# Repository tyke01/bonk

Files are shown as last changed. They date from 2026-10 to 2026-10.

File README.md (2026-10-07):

# BONK

**An open-source handheld RC transmitter built around the ESP32.**
Designed by Spectral Systems.

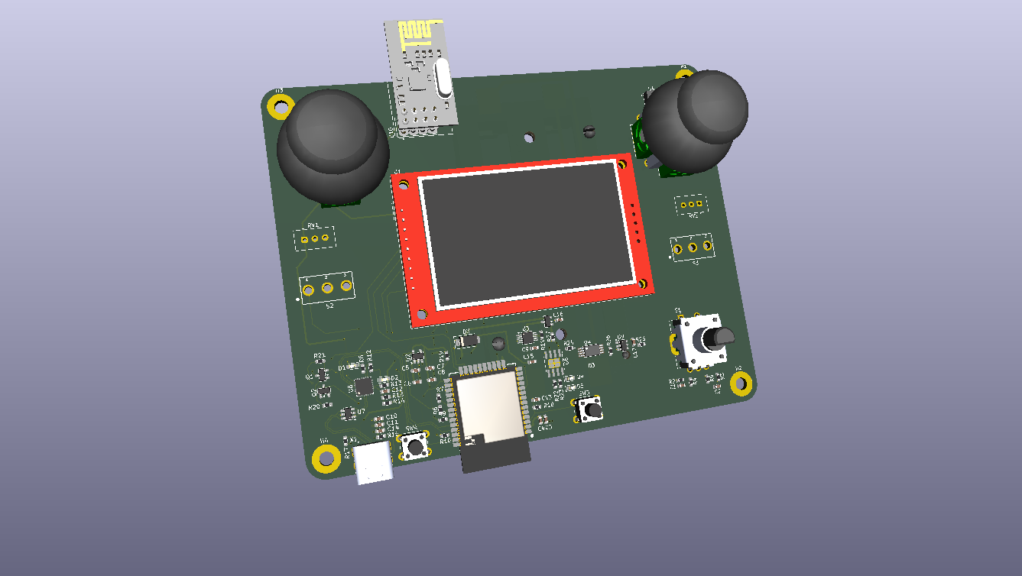
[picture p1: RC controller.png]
BONK PCB render


> **Status: Rev 1 (first PCB revision).** The schematic passes ERC with 0 errors and the PCB passes DRC. Boards have been ordered but **not yet assembled or tested**, so expect errata. See [Known issues](#known-issues-rev-1) before building one.

---

## Contents

- [Features](#features)
- [Repository layout](#repository-layout)
- [Hardware overview](#hardware-overview)
- [Power architecture](#power-architecture)
- [ESP32 pin map](#esp32-pin-map)
- [Buses and addresses](#buses-and-addresses)
- [Firmware notes](#firmware-notes)
- [Bill of materials](#bill-of-materials)
- [Manufacturing](#manufacturing)
- [Assembly](#assembly)
- [Bring-up checklist](#bring-up-checklist)
- [Known issues (Rev 1)](#known-issues-rev-1)
- [License](#license)

---

## Features

- **MCU:** ESP32 module (Ai-Thinker ESP32-SL) with on-board PCB antenna
- **Inputs:** 2 analog joysticks, 2 potentiometers, 2 toggle switches, a rotary encoder with push switch, and BOOT/EN buttons
- **Display:** 2.8" ILI9341 320x240 SPI TFT module (its SD card slot is not used)
- **Radio:** nRF24L01 breakout on the shared SPI bus. ESP-NOW/WiFi/BLE are also available from the ESP32 itself
- **USB-C:** programming and charging through a CP2102N USB-UART bridge with automatic reset into the bootloader
- **Battery:** 2x 18650 cells in parallel (1S), with a TP4056 charger, DW01A + FS8205A protection, and USB/battery load sharing
- **Battery monitoring:** INA226 voltage and current monitor on I2C, which measures both charge and discharge current
- **PCB:** 4 layers, 125 x 100 mm, 1.6 mm thick

---

## Repository layout

```
RC controller.kicad_pro     KiCad project
RC controller.kicad_sch     Schematic (single sheet, with design notes)
RC controller.kicad_pcb     PCB layout
RC controller.png           3D render
bom/
  ibom.html                 Interactive BOM (open in a browser for assembly)
  RC controller.csv         Raw BOM export
production/
  RC_controller.zip         Gerbers + drill files, ready to upload to JLCPCB
  bom.csv                   BOM for JLCPCB assembly
  positions.csv             Pick-and-place (CPL) file
  designators.csv
  netlist.ipc               IPC netlist (lets the fab run electrical tests)
placement/
  RC controller-all.pos     KiCad component placement file
```

Designed in **KiCad 10.0.6**. Open `RC controller.kicad_pro` to view everything.

---

## Hardware overview

| Block | Main parts | Notes |
|---|---|---|
| MCU | L1 ESP32-SL | Antenna overhangs the bottom board edge |
| USB-UART | U8 CP2102N (QFN-24), Q1/Q2 BC817 | DTR/RTS drive EN and IO0 for automatic bootloader entry |
| USB-C | X1 GCT USB4085-GF-A, U7 USBLC6-2SC6 | 5.1k pull-downs on CC1/CC2 (sink, default 5 V). USBLC6 provides ESD protection on D+/D- |
| Charger | U6 TP4056 (ESOP-8) | About 1.1 A charge current, set by R24 |
| Protection | U9 DW01A, Q4 FS8205A | Disconnects the cells on overcharge, overdischarge, or overcurrent |
| Load sharing | Q3 AO3401A, D3 SS34 | Runs the system from USB when plugged in, otherwise from the battery |
| Regulator | U2 AP2112K-3.3 | 600 mA LDO, single 3.3 V rail for everything |
| Battery monitor | U3 INA226, R11 20 mΩ | I2C address 0x40 |
| Display | U1 ILI9341 2.8" SPI module | Powered from 3.3 V |
| Radio | U10 nRF24L01 breakout | Shares the SPI bus with the display |
| Sticks | U4/U5 SparkFun COM-09032 | Powered from 3.3 V |
| Pots | RV1/RV2 | Powered from 3.3 V |
| Encoder | S1 Bourns PEC12R-4217F-S0024 | 10k pull-ups plus 10k/10 nF RC hardware debounce |
| Toggles | S2/S3 Würth 472123010111 | Switch to GND |
| Buttons | SW3 (EN/reset), SW4 (BOOT) | R18/C13 delay the release of EN at power-up |
| Battery holder | BT1 Keystone 1048 | 2x 18650, **mounted on the bottom side** |

---

## Power architecture

### Net names

| Net | What it is |
|---|---|
| `+5V` | USB VBUS |
| `+VBAT_IN` | Cell positive terminal |
| `BAT_P` | Battery positive after the shunt. Charger output and Q3 drain connect here |
| `+VBAT_OUT` | **System rail (VSYS).** Feeds the 3.3 V regulator |
| `+3V3` | Regulated 3.3 V for all logic |
| `BAT-` | Raw cell negative |
| `GND` | System ground (the switched negative, P-). Connected to `BAT-` through Q4 |

### Charging path

`TP4056 BAT → BAT_P → R11 shunt → +VBAT_IN → cells → BAT- → Q4 (FS8205A) → GND → back to the TP4056`

The return path goes through the protection MOSFETs. That's what allows the DW01A to stop charging if a cell reaches its overcharge limit.

### Load sharing

- **USB connected:** 5 V feeds `+VBAT_OUT` through D3 (about 4.5 V). Q3's gate sits at 5 V, so Q3 is off, and its body diode is reverse biased. The battery is isolated from the load and only the charger talks to it. Charge termination is therefore not confused by system current.
- **USB disconnected:** R27 pulls Q3's gate to GND, Q3 turns on, and the battery powers `+VBAT_OUT` through Q3's low channel resistance. D3 blocks the battery from back-feeding the USB side.
- **During the handover,** Q3's body diode keeps the rail up so the ESP32 doesn't brown out.

### Protection

The DW01A watches the cell voltage and the voltage drop across the FS8205A. If it detects overcharge, overdischarge, or overcurrent, it turns off one of the two MOSFETs and disconnects `BAT-` from `GND`. R26 only feeds the DW01A's CS sense pin and carries no load current.

### Battery monitoring

R11 (20 mΩ) is in series with the battery, so the INA226 sees both directions of current:

- **Positive current = discharging**
- **Negative current = charging**

The full-scale range is about ±4 A (81.92 mV / 20 mΩ). The INA226's Vin+/Vin- traces are Kelvin-connected directly at R11's pads.

---

## ESP32 pin map

| GPIO | Module pin | Net | Function |
|---|---|---|---|
| 36 (SENSOR_VP) | 4 | `JL_LR` | Left stick X |
| 39 (SENSOR_VN) | 5 | `JL_UD` | Left stick Y (throttle) |
| 34 | 6 | `JR_LR` | Right stick X |
| 35 | 7 | `JR_UD` | Right stick Y |
| 32 | 8 | `POT_L` | Left potentiometer |
| 33 | 9 | `POT_R` | Right potentiometer |
| 25 | 10 | `SW_L` | Left toggle switch (to GND) |
| 26 | 11 | `SW_R` | Right toggle switch (to GND) |
| 27 | 12 | `CLK` | Encoder channel A |
| 14 | 13 | `DT` | Encoder channel B |
| 16 | 27 | `SW` | Encoder push switch (to GND) |
| 13 | 16 | `LED` | TFT backlight |
| 15 | 23 | `CS` | TFT chip select |
| 2 | 24 | `DC` | TFT data/command |
| 5 | 29 | `CSN` | nRF24 chip select |
| 4 | 26 | `CE` | nRF24 chip enable |
| 18 | 30 | `SCK` | SPI clock (through R7, 50 Ω) |
| 19 | 31 | `MISO` | SPI MISO (through R6, 50 Ω) |
| 23 | 37 | `MOSI` | SPI MOSI |
| 21 | 33 | `SDA` | I2C data |
| 22 | 36 | `SCL` | I2C clock |
| 1 (TXD0) | 35 | | To CP2102N RXD |
| 3 (RXD0) | 34 | | From CP2102N TXD |
| 0 | 25 | `BOOT` | BOOT button and auto-reset |
| EN | 3 | `RST` | Reset button, auto-reset, and TFT reset |

**Unused:** IO12 and IO17. The SD0 to SD3, CMD and CLK pins are reserved for the module's flash and must stay unconnected.

**Why these pins:**

- All analog inputs (sticks and pots) are on **ADC1** pins, because ADC2 can't be used while WiFi (including ESP-NOW) is active.
- GPIO34 to 39 are **input-only with no internal pull-ups**, which makes them a good fit for the analog sticks.
- IO0, IO2, IO5, IO12 and IO15 are **strapping pins**. Nothing on the board forces them to a level that would break booting. IO12 is deliberately left unconnected.

---

## Buses and addresses

### SPI (shared)

| Device | Chip select | Other pins |
|---|---|---|
| ILI9341 TFT | IO15 (`CS`) | DC = IO2, reset = EN, backlight = IO13 |
| nRF24L01 | IO5 (`CSN`) | CE = IO4, IRQ not connected |

SCK = IO18, MOSI = IO23, MISO = IO19. Only one device is selected at a time.

### I2C

| Device | Address | Pull-ups |
|---|---|---|
| INA226 | 0x40 (A0 = A1 = GND) | R9/R10, 4.7k to 3.3 V |

---

## Firmware notes

Firmware is developed separately with **PlatformIO** (Arduino framework). The following points are for anyone writing firmware for this board:

- **Toggle switches and the encoder push switch** (IO25, IO26, IO16) have **no external pull-ups**. Use `INPUT_PULLUP`. A closed switch reads LOW.
- **Encoder A/B** (IO27, IO14) already have 10k external pull-ups and RC debounce.
- **TFT_eSPI configuration:** MISO 19, MOSI 23, SCLK 18, CS 15, DC 2, RST -1 (tied to EN), backlight 13. The breadboard prototype used `setRotation(3)`; check that this still fits the PCB orientation.
- **INA226:** address 0x40, shunt 0.020 Ω. Discharge reads positive, charging reads negative.
- **Low-battery cutoff:** the AP2112K is an LDO. Once the battery falls below roughly 3.5 V, the 3.3 V rail starts following it down. Use the INA226 bus voltage to warn the user, and shut down before the DW01A's overdischarge protection trips.
- **Uploading:** the CP2102N's DTR/RTS lines drive EN and IO0 through Q1/Q2, so uploads should start automatically. If they don't, hold BOOT, tap EN, then release BOOT.

---

## Bill of materials

LCSC numbers are the parts matched for the Rev 1 JLCPCB order. **Stock and part numbers change, so verify each one before ordering.** Full BOM files are in `bom/` and `production/`.

| Designator | Value | Package | LCSC | Assembled by |
|---|---|---|---|---|
| C1, C2 | 10 nF 50 V X7R | 0603 | C57112 | JLC |
| C3, C5, C7, C9, C10, C14, C17 | 100 nF 50 V X7R | 0603 | C14663 | JLC |
| C11 | 4.7 µF 16 V X5R | 0603 | C19666 | JLC |
| C12, C13 | 1 µF 50 V X5R | 0603 | C15849 | JLC |
| C4, C6, C8, C15, C16 | 10 µF 10 V X5R | 0603 | C19702 | JLC |
| D1, D2, D4, D5 | LED, green | 0603 | C2289 (verify colour and Vf) | JLC |
| D3 | SS34 Schottky | SMA | C8678 | JLC |
| Q1, Q2 | BC817 NPN | SOT-23 | C22400355 | JLC |
| Q3 | AO3401A P-FET | SOT-23 | C15127 | JLC |
| Q4 | FS8205A dual N-FET | **TSSOP-8** | Choose a TSSOP-8 variant (see Known issues) | JLC |
| R2-R5, R18-R21 | 10k 1% | 0603 | C25804 | JLC |
| R6, R7 | 50 Ω | 0603 | C849792 | JLC |
| R8, R12 | 470 Ω 1% | 0603 | C23179 | JLC |
| R9, R10 | 4.7k 1% | 0603 | C23162 | JLC |
| R11 | 20 mΩ 1% 1 W current sense | 1206 | C7420010 | JLC |
| R13, R22, R23, R26 | 1k 1% | 0603 | C21190 | JLC |
| R14 | 47.5k 1% | 0603 | C137715 | JLC |
| R15 | 22.1k 1% | 0603 | C2960862 | JLC |
| R16, R17 | 5.1k 1% | 0603 | C23186 | JLC |
| R24 | 1.1k 1% | 0603 | C54531154 | JLC |
| R25 | 100 Ω 1% | 0603 | C22775 | JLC |
| R27 | 100k 1% | 0603 | C25803 | JLC |
| U2 | AP2112K-3.3 | SOT-23-5 | C23380830 | JLC |
| U3 | INA226 | VSSOP-10 | C49851 | JLC |
| U6 | TP4056 | ESOP-8 | C16581 | JLC |
| U7 | USBLC6-2SC6 | SOT-23-6 | C2827654 | JLC |
| U8 | CP2102N-A02-GQFN24 | QFN-24 4x4 | C969151 | JLC |
| U9 | DW01A | SOT-23-6 | C351410 | JLC |
| L1 | ESP32-SL module | SMD module | C2764058 | Hand (was out of stock) |
| X1 | USB4085-GF-A USB-C | Through-hole | C7095263 | Hand |
| S1 | PEC12R-4217F-S0024 encoder | Through-hole | C49671241 | Hand |
| S2, S3 | 472123010111 toggle | Through-hole | C20040218 | Hand |
| U4, U5 | SparkFun COM-09032 joystick | Through-hole | C3283715 | Hand |
| RV1, RV2 | Potentiometer | Vishay T93YA footprint | | Hand |
| SW3, SW4 | Tactile switch 6 mm | Through-hole | | Hand |
| U1 | 2.8" ILI9341 SPI TFT module | Header | | Hand |
| U10 | nRF24L01 breakout | 2x4 header | | Hand |
| BT1 | Keystone 1048 2x 18650 holder | SMD, bottom side | | Hand |

---

## Manufacturing

Fabricated at **JLCPCB**. Upload `production/RC_controller.zip`.

| Setting | Value |
|---|---|
| Layers | 4 |
| Size | 125 x 100 mm |
| Thickness | 1.6 mm |
| Outer copper | 1 oz |
| Surface finish | HASL works for hand soldering. ENIG is better for the 0.5 mm pitch parts (U3, U8) |

**Stackup:**

| Layer | Use |
|---|---|
| F.Cu | Signals and components, with GND pour |
| In1.Cu | Solid GND plane |
| In2.Cu | GND plane |
| B.Cu | Signals, plus the battery holder |

**Design rules used:** 0.2 mm default tracks and clearance, 0.5 mm power tracks, 1.0 mm battery tracks, 0.6/0.3 mm vias. USB D+/D- are routed as a differential pair over the In1 GND plane. There is a copper keepout under the ESP32 antenna on all layers.

**Notes:**

- The USB-C connector (X1) has very fine pin spacing, so the board allows bridged solder-mask openings between its pads. Take care not to bridge pins when soldering it.
- U6 (TP4056) uses a modified footprint with 0.3 mm thermal vias, and pad B12 on X1 has a solid zone connection. Both changes are stored on the board, so don't run "Update Footprints from Library" on U6 or X1 without reapplying them.

---

## Assembly

The Rev 1 order uses **JLCPCB partial assembly**: JLC places the SMT parts on the top side, and the rest is hand-soldered.

**Before ordering assembly:**

1. **Q4 must be a TSSOP-8 part.** JLC's automatic match picked a SOT-23-6 FS8205A, which will not fit the footprint. Open the part details and confirm the package.
2. **Check every rotation** in the placement preview: U8, U3, U6, U9, U2, U7, Q1 to Q4, D3 (cathode band) and the LEDs. Compare each part's pin 1 with the pin-1 mark on the silkscreen.
3. **Mounting holes H1 to H4** appear in the CPL but not in the BOM. JLC warns about this; it's safe to continue.

**Hand-soldering order (suggested):**

1. ESP32-SL module (L1)
2. USB-C connector (X1)
3. Battery holder (BT1, bottom side)
4. Buttons, toggles, encoder, pots
5. Joysticks
6. Display and nRF24 headers last, since they cover other parts

The interactive BOM (`bom/ibom.html`) highlights where each part goes.

---

## Bring-up checklist

Work through this in order, and **don't insert the cells until step 4.**

1. **Visual inspection.** Look for solder bridges, especially on U8, U3 and X1.
2. **Short-circuit check (power off).** Measure resistance from GND to `+5V`, `+VBAT_OUT`, `+3V3` and `BAT_P`. None of them should read close to 0 Ω.
3. **USB power, no cells, ideally before soldering the ESP32.** Use a current-limited supply or a USB power meter if you have one. Expect:
   - `+5V` ≈ 5 V
   - `+VBAT_OUT` ≈ 4.5 V (5 V minus the SS34 drop)
   - `+3V3` ≈ 3.3 V
4. **Insert the cells.** Check polarity. **Both cells must be at about the same voltage before you insert them**, because cells in parallel at different voltages push a large current into each other. If the board doesn't run from the battery after you insert the cells, plug in USB once: some DW01-based circuits need a charger connection to leave the protected state.
5. **Charging.** With USB connected, the charge LED should light, and the INA226 should report a negative current.
6. **USB-UART.** Connect to a PC and confirm the CP2102N appears as a serial port. Older systems may need Silicon Labs' CP210x driver.
7. **Firmware.** Upload a test sketch. Uploads should start without pressing BOOT, thanks to auto-reset.
8. **Peripherals, one at a time:** display, sticks and pots, switches and encoder, INA226, nRF24.

---

## Known issues (Rev 1)

- **Q4 package:** see [Assembly](#assembly). Make sure a TSSOP-8 FS8205A is placed.
- **No dedicated bulk capacitor at the nRF24.** nRF24L01 modules are known to need a local bulk capacitor for stable operation. If the radio is unreliable, solder a 10 to 100 µF capacitor across the module's VCC and GND pins. Add a footprint for it in Rev 2.
- **10 µF capacitors are 10 V, 0603.** At 5 V, DC bias derating significantly reduces their effective capacitance. Consider 16 V or higher, or 0805, in Rev 2.
- **Shared MISO.** The ILI9341 and the nRF24 share MISO. Some ILI9341 modules reportedly don't release MISO when deselected, which can corrupt nRF24 reads. If this happens, disconnect the display's MISO; the display only needs MISO for read-back.
- **3.3 V regulation at low battery.** The AP2112K is an LDO, so below about 3.5 V battery the 3.3 V rail drops with it. Handle this with a firmware cutoff.
- **R6/R7 = 50 Ω** is a non-standard value (0.1% thin-film part). 51 Ω works the same and is cheaper to source.
- **LED forward voltage.** D1 and D2 are powered from 3.3 V through 470 Ω. Pick LEDs with a forward voltage around 2 V. Some "green" 0603 LEDs are about 3 V and will be very dim at 3.3 V.

---

## License

The hardware design files are licensed under the **CERN Open Hardware Licence Version 2, Permissive (CERN-OHL-P-2.0)**. See the `LICENSE` file.

Under this licence you may use, study, modify, make and sell the design, as long as you keep the copyright and licence notices. Firmware, once published, will be licensed separately.

---

## Credits

Designed by **Victor Macharia (Syb0rg)**, Spectral Systems.
Repository: [github.com/tyke01/bonk](https://github.com/tyke01/bonk)

Contributions, issue reports, and build photos are welcome. Please open an issue if you build one.

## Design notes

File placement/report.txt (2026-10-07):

Placement file: 'C:\Users\Victor\Documents\KICAD_PROJECTS\RC controller\placement\RC controller-all.pos'.
Info: Component count: 58.
Info: Done.

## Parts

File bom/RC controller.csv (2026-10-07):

Id | Designator | Footprint | Quantity | Designation | Supplier and ref
1 | BT1 | Battery_Holder_18650_2_Cell_SMD | 1 | 1048
2 | C1, C2 | C_0603_1608Metric | 2 | 10nf
3 | C3, C5, C7, C9, C10, C14, C17 | C_0603_1608Metric | 7 | 0.1u
4 | C4, C6, C8, C15, C16 | C_0603_1608Metric | 5 | 10u
5 | C11 | C_0603_1608Metric | 1 | 4.7u
6 | C12, C13 | C_0603_1608Metric | 2 | 1u
7 | D1, D2, D4, D5 | LED_0603_1608Metric_Pad1.05x0.95mm_HandSolder | 4 | LED
8 | D3 | D_SMA | 1 | SS34
9 | L1 | WIFIM-SMD_ESP32-SL | 1 | ESP32-SL
10 | Q1, Q2 | SOT-23 | 2 | BC817
11 | Q3 | SOT-23 | 1 | AO3401A
12 | Q4 | SOP65P640X120-8N | 1 | FS8205A
13 | R2, R3, R4, R5, R18, R19, R20, R21 | R_0603_1608Metric | 8 | 10K
14 | R6, R7 | R_0603_1608Metric | 2 | 50
15 | R8, R12 | R_0603_1608Metric | 2 | 470
16 | R9, R10 | R_0603_1608Metric | 2 | 4k7
17 | R11 | R_1206_3216Metric_Pad1.30x1.75mm_HandSolder | 1 | 20m
18 | R13, R22, R23, R26 | R_0603_1608Metric | 4 | 1k
19 | R14 | R_0603_1608Metric | 1 | 47k5
20 | R15 | R_0603_1608Metric | 1 | 22k1
21 | R16, R17 | R_0603_1608Metric | 2 | 5k1
22 | R24 | R_0603_1608Metric | 1 | 1k1
23 | R25 | R_0603_1608Metric | 1 | 100
24 | R27 | R_0603_1608Metric | 1 | 100k
25 | RV1, RV2 | Potentiometer_Vishay_T93YA_Vertical | 2 | R_Potentiometer
26 | S1 | XDCR_PEC12R-4217F-S0024 | 1 | PEC12R-4217F-S0024
27 | S2, S3 | toggle_switch | 2 | 472123010111
28 | SW3, SW4 | SW_PUSH_6mm_H7.3mm | 2 | SW_Push
29 | U1 | CR2013-MI2120 | 1 | CR2013-MI2120
30 | U2 | SOT-23-5 | 1 | AP2112K-3.3
31 | U3 | TSSOP-10_3x3mm_P0.5mm | 1 | INA226
32 | U4, U5 | XDCR_COM-09032 | 2 | COM-09032
33 | U6 | SOIC-8-1EP_3.9x4.9mm_P1.27mm_EP2.41x3.3mm_ThermalVias | 1 | TP4056-42-ESOP8
34 | U7 | SOT-23-6 | 1 | USBLC6-2SC6
35 | U8 | QFN-24-1EP_4x4mm_P0.5mm_EP2.6x2.6mm | 1 | CP2102N-Axx-xQFN24
36 | U9 | SOT-23-6 | 1 | DW01A
37 | U10 | nRF24L01_Breakout | 1 | NRF24L01_Breakout
38 | X1 | USB4085_CONNECTOR | 1 | USB4085-GF-A

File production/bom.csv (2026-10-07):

Designator | Footprint | Quantity | Value | LCSC Part #
BT1 | Battery_Holder_18650_2_Cell_SMD | 1 | 1048
C1, C2 | 0603 | 2 | 10nf
C10, C14, C17, C3, C5, C7, C9 | 0603 | 7 | 0.1u
C11 | 0603 | 1 | 4.7u
C12, C13 | 0603 | 2 | 1u
C15, C16, C4, C6, C8 | 0603 | 5 | 10u
D1, D2, D4, D5 | 0603 | 4 | LED
D3 | D_SMA | 1 | SS34
L1 | WIFIM-SMD_ESP32-SL | 1 | ESP32-SL | C2764058
Q1, Q2 | SOT-23 | 2 | BC817
Q3 | SOT-23 | 1 | AO3401A
Q4 | SOP65P640X120-8N | 1 | FS8205A
R10, R9 | 0603 | 2 | 4k7
R11 | 1206 | 1 | 20m
R12, R8 | 0603 | 2 | 470
R13, R22, R23, R26 | 0603 | 4 | 1k
R14 | 0603 | 1 | 47k5
R15 | 0603 | 1 | 22k1
R16, R17 | 0603 | 2 | 5k1
R18, R19, R2, R20, R21, R3, R4, R5 | 0603 | 8 | 10K
R24 | 0603 | 1 | 1k1
R25 | 0603 | 1 | 100
R27 | 0603 | 1 | 100k
R6, R7 | 0603 | 2 | 50
RV1, RV2 | Potentiometer_Vishay_T93YA_Vertical | 2 | R_Potentiometer
S1 | XDCR_PEC12R-4217F-S0024 | 1 | PEC12R-4217F-S0024
S2, S3 | toggle_switch | 2 | 472123010111
SW3, SW4 | SW_PUSH_6mm_H7.3mm | 2 | SW_Push
U1 | CR2013-MI2120 | 1 | CR2013-MI2120
U10 | nRF24L01_Breakout | 1 | NRF24L01_Breakout
U2 | SOT-23-5 | 1 | AP2112K-3.3
U3 | TSSOP-10_3x3mm_P0.5mm | 1 | INA226
U4, U5 | XDCR_COM-09032 | 2 | COM-09032
U6 | SOIC-8-1EP_3.9x4.9mm_P1.27mm_EP2.41x3.3mm_ThermalVias | 1 | TP4056-42-ESOP8
U7 | SOT-23-6 | 1 | USBLC6-2SC6
U8 | QFN-24-1EP_4x4mm_P0.5mm_EP2.6x2.6mm | 1 | CP2102N-Axx-xQFN24
U9 | SOT-23-6 | 1 | DW01A
X1 | USB4085_CONNECTOR | 1 | USB4085-GF-A

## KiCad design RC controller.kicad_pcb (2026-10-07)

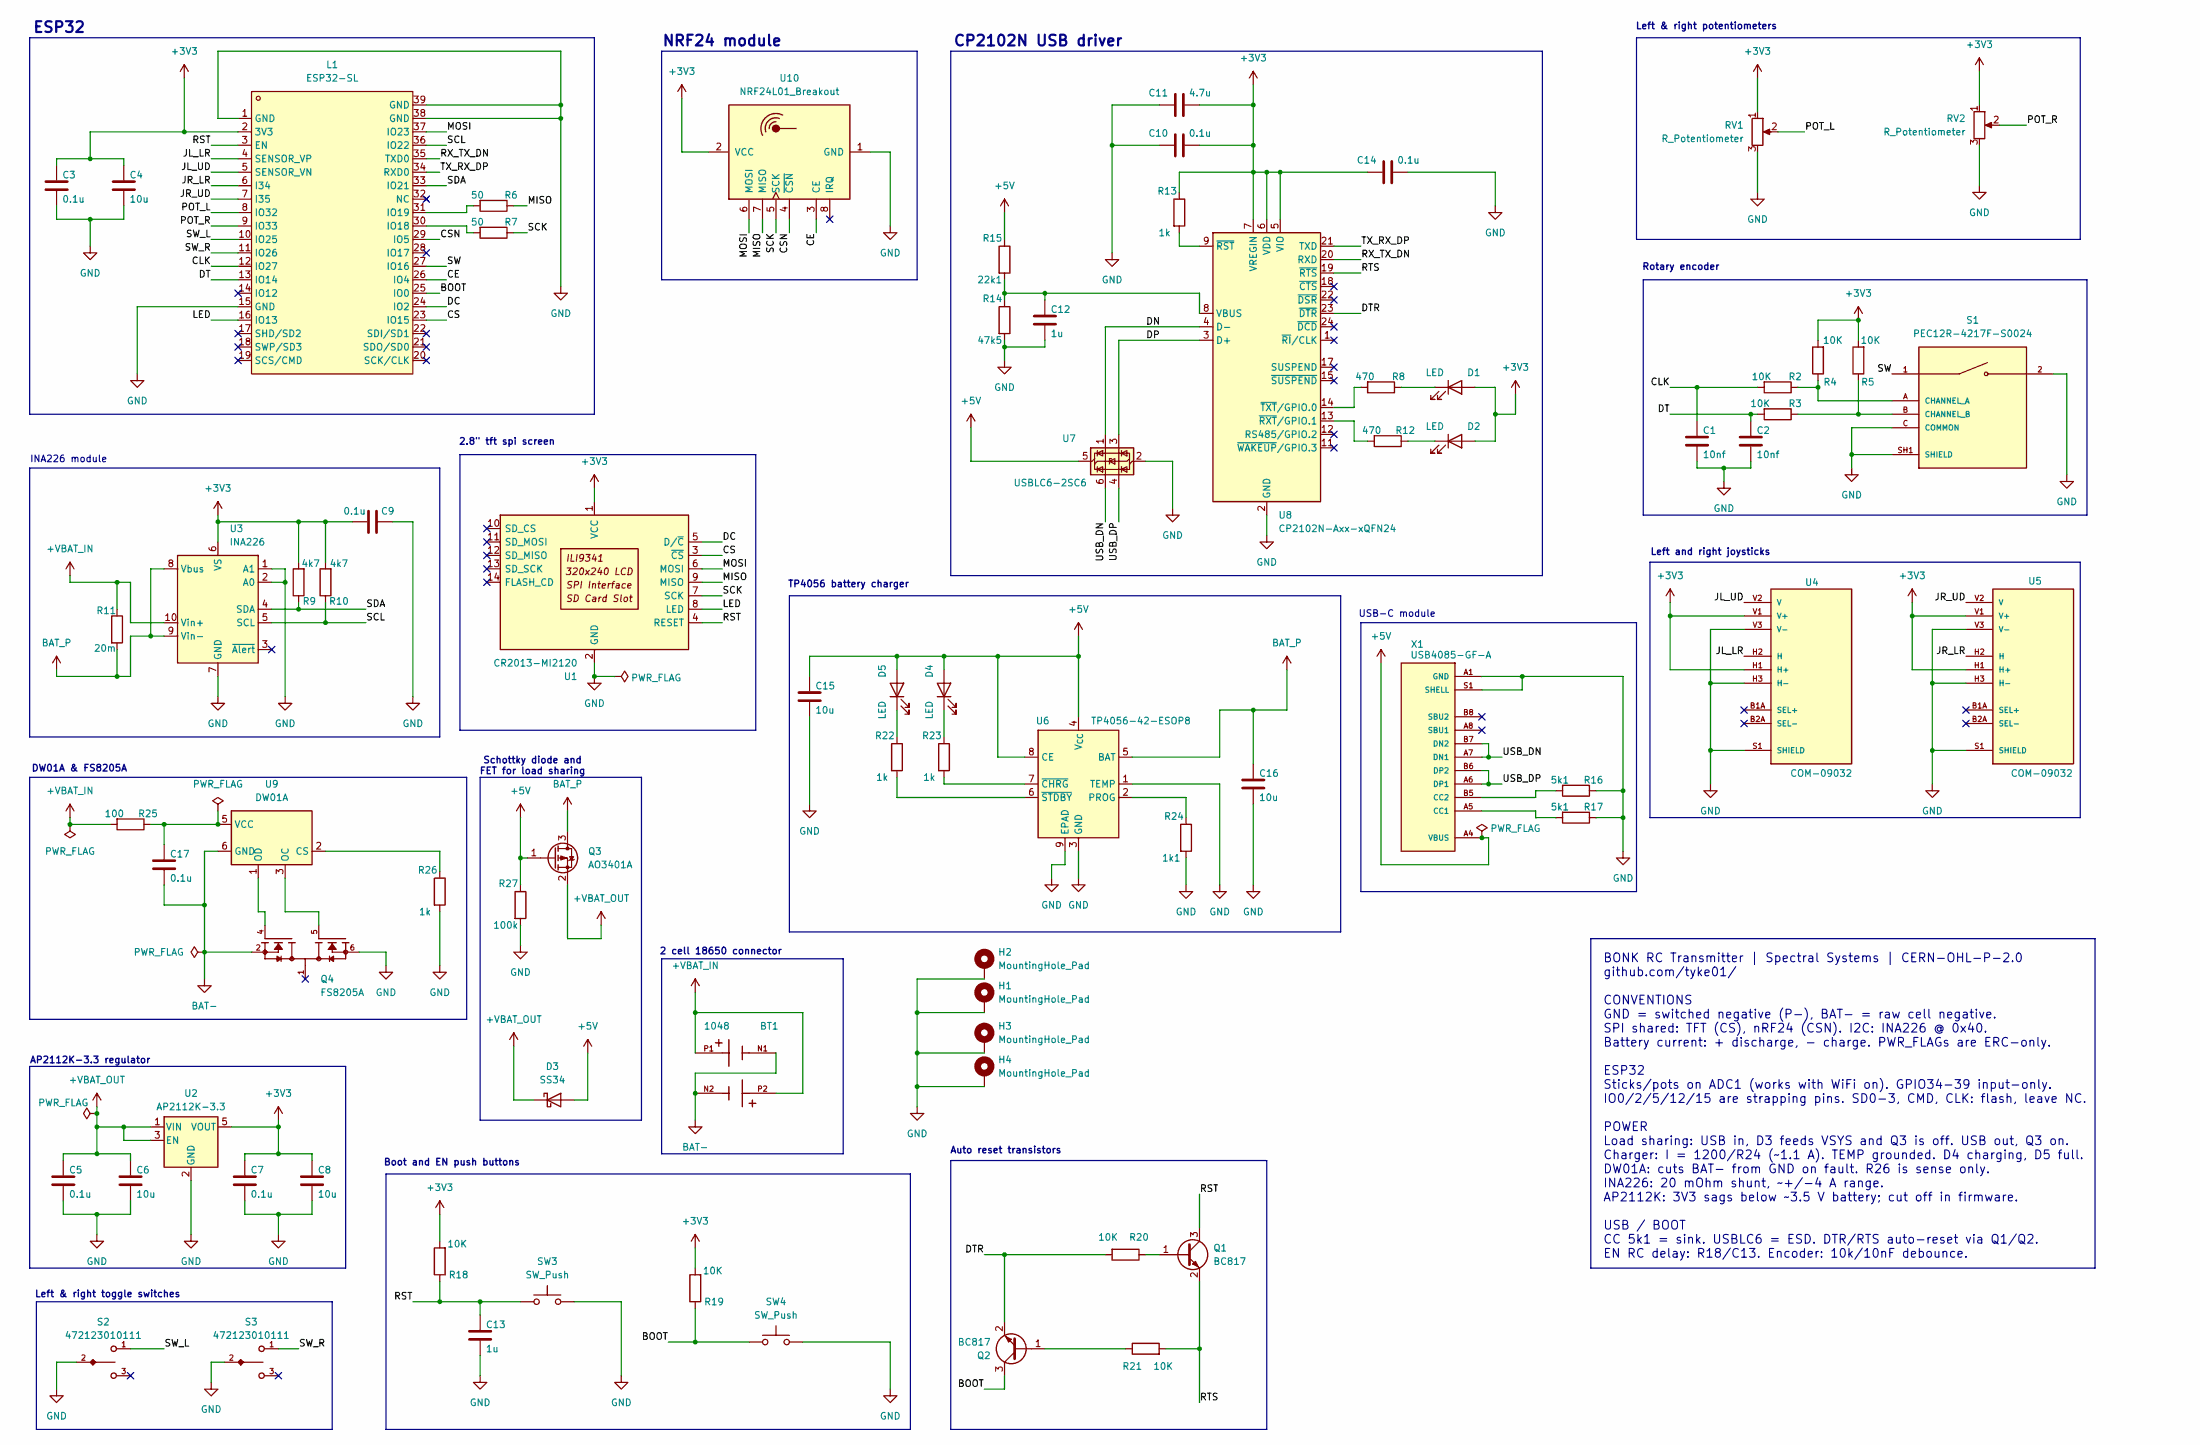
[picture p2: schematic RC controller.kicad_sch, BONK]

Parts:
BT1: 1048; Battery_Holder_18650_2_Cell_SMD; PARTREV A
C1, C2: 10nf; C_0603_1608Metric
C3, C5, C7, C9, C10, C14, C17: 0.1u; C_0603_1608Metric
C4, C6, C8, C15, C16: 10u; C_0603_1608Metric
C11: 4.7u; C_0603_1608Metric
C12, C13: 1u; C_0603_1608Metric
D1, D2, D4, D5: LED; LED_0603_1608Metric_Pad1.05x0.95mm_HandSolder
D3: SS34; D_SMA
H1, H2, H3, H4: MountingHole_Pad; MountingHole_3.5mm_Pad
L1: ESP32-SL; WIFIM-SMD_ESP32-SL; MPN ESP32-SL; LCSC Part C2764058
Q1, Q2: BC817; SOT-23
Q3: AO3401A; SOT-23
Q4: FS8205A; SOP65P640X120-8N; PARTREV 1.7
R2, R3, R4, R5, R18, R19, R20, R21: 10K; R_0603_1608Metric
R6, R7: 50; R_0603_1608Metric
R8, R12: 470; R_0603_1608Metric
R9, R10: 4k7; R_0603_1608Metric
R11: 20m; R_1206_3216Metric_Pad1.30x1.75mm_HandSolder
R13, R22, R23, R26: 1k; R_0603_1608Metric
R14: 47k5; R_0603_1608Metric
R15: 22k1; R_0603_1608Metric
R16, R17: 5k1; R_0603_1608Metric
R24: 1k1; R_0603_1608Metric
R25: 100; R_0603_1608Metric
R27: 100k; R_0603_1608Metric
RV1, RV2: R_Potentiometer; Potentiometer_Vishay_T93YA_Vertical
S1: PEC12R-4217F-S0024; XDCR_PEC12R-4217F-S0024; PARTREV 07/21
S2, S3: 472123010111; toggle_switch
SW3, SW4: SW_Push; SW_PUSH_6mm_H7.3mm
U1: CR2013-MI2120
U2: AP2112K-3.3; SOT-23-5
U3: INA226; TSSOP-10_3x3mm_P0.5mm
U4, U5: COM-09032; XDCR_COM-09032; PARTREV N/A
U6: TP4056-42-ESOP8; SOIC-8-1EP_3.9x4.9mm_P1.27mm_EP2.41x3.3mm_ThermalVias
U7: USBLC6-2SC6; SOT-23-6
U8: CP2102N-Axx-xQFN24; QFN-24-1EP_4x4mm_P0.5mm_EP2.6x2.6mm
U9: DW01A; SOT-23-6
U10: NRF24L01_Breakout; nRF24L01_Breakout
X1: USB4085-GF-A; USB4085_CONNECTOR

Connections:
+3V3: C3.1, C4.1, C7.1, C8.1, C9.2, C10.2, C11.2, C14.1, D1.2 (A), D2.2 (A), L1.2 (3V3), R4.2, R5.2, R9.2, R10.2, R13.1, R18.2, R19.2, RV1.1, RV2.1, U1.1 (VCC), U2.5 (VOUT), U3.6 (VS), U4.H1 (H+), U4.V1 (V+), U5.H1 (H+), U5.V1 (V+), U8.5 (VIO), U8.6 (VDD), U8.7 (VREGIN), U10.2 (VCC)
+5V: C15.1, D3.2 (A), D4.2 (A), D5.2 (A), Q3.1 (G), R15.1, R27.1, U6.4 (V_{CC}), U6.8 (CE), U7.5 (VBUS), X1.A4 (VBUS), X1.A9 (VBUS), X1.B4 (VBUS), X1.B9 (VBUS)
+VBAT_IN: BT1.P1, BT1.P2, R11.1, R25.2, U3.10 (Vin+)
+VBAT_OUT: C5.1, C6.1, D3.1 (K), Q3.2 (S), U2.1 (VIN), U2.3 (EN)
/BOOT: L1.25 (IO0), Q2.3 (C), R19.1, SW4.1
/CE: L1.26 (IO4), U10.3 (CE)
/CLK: C1.1, L1.12 (IO27), R2.2
/CS: L1.23 (IO15), U1.3 (~CS)
/CSN: L1.29 (IO5), U10.4 (~CSN)
/DC: L1.24 (IO2), U1.5 (D/~C)
/DN: U7.1 (I/O1), U8.4 (D-)
/DP: U7.3 (I/O2), U8.3 (D+)
/DT: C2.1, L1.13 (IO14), R3.2
/DTR: Q2.2 (E), R20.2, U8.23 (~DTR)
/JL_LR: L1.4 (SENSOR_VP), U4.H2 (H)
/JL_UD: L1.5 (SENSOR_VN), U4.V2 (V)
/JR_LR: L1.6 (I34), U5.H2 (H)
/JR_UD: L1.7 (I35), U5.V2 (V)
/LED: L1.16 (IO13), U1.8 (LED)
/MISO: R6.1, U1.9 (MISO), U10.7 (MISO)
/MOSI: L1.37 (IO23), U1.6 (MOSI), U10.6 (MOSI)
/POT_L: L1.8 (IO32), RV1.2
/POT_R: L1.9 (IO33), RV2.2
/RST: C13.1, L1.3 (EN), Q1.3 (C), R18.1, SW3.1, U1.4 (RESET)
/RTS: Q1.2 (E), R21.2, U8.19 (~RTS)
/RX_TX_DN: L1.35 (TXD0), U8.20 (RXD)
/SCK: R7.1, U1.7 (SCK), U10.5 (SCK)
/SCL: L1.36 (IO22), R10.1, U3.5 (SCL)
/SDA: L1.33 (IO21), R9.1, U3.4 (SDA)
/SW: L1.27 (IO16), S1.1
/SW_L: L1.10 (IO25), S2.1
/SW_R: L1.11 (IO26), S3.1
/TX_RX_DP: L1.34 (RXD0), U8.21 (TXD)
/USB_DN: U7.6 (I/O1), X1.A7 (DN1), X1.B7 (DN2)
/USB_DP: U7.4 (I/O2), X1.A6 (DP1), X1.B6 (DP2)
BAT-: BT1.N1, BT1.N2, C17.2, Q4.2, Q4.3, U9.6 (GND)
BAT_P: C16.1, Q3.3 (D), R11.2, U3.8 (Vbus), U3.9 (Vin-), U6.5 (BAT)
GND: C1.2, C2.2, C3.2, C4.2, C5.2, C6.2, C7.2, C8.2, C9.1, C10.1, C11.1, C12.2, C13.2, C14.2, C15.2, C16.2, H1.1 (1_1), H2.1 (1_1), H3.1 (1_1), H4.1 (1_1), L1.1 (GND), L1.15 (GND), L1.38 (GND), L1.39 (GND), Q4.6, Q4.7, R14.2, R16.1, R17.1, R24.2, R26.2, R27.2, RV1.3, RV2.3, S1.2, S1.C (COMMON), S1.SH1 (SHIELD), S1.SH2 (SHIELD), S2.2, S3.2, SW3.2, SW4.2, U1.2 (GND), U2.2 (GND), U3.1 (A1), U3.2 (A0), U3.7 (GND), U4.H3 (H-), U4.S1 (SHIELD), U4.S2 (SHIELD), U4.S3 (SHIELD), U4.S4 (SHIELD), U4.V3 (V-), U5.H3 (H-), U5.S1 (SHIELD), U5.S2 (SHIELD), U5.S3 (SHIELD), U5.S4 (SHIELD), U5.V3 (V-), U6.1 (TEMP), U6.3 (GND), U6.9 (EPAD), U7.2 (GND), U8.2 (GND), U8.25 (GND), U10.1 (GND), X1.A1 (GND), X1.A12 (GND), X1.B1 (GND), X1.B12 (GND), X1.S1 (SHELL), X1.S2 (SHELL), X1.S3 (SHELL), X1.S4 (SHELL)
unnamed: D1.1 (K), R8.1
unnamed: D2.1 (K), R12.1
unnamed: D4.1 (K), R23.1
unnamed: D5.1 (K), R22.1
unnamed: L1.30 (IO18), R7.2
unnamed: L1.31 (IO19), R6.2
unnamed: Q1.1 (B), R20.1
unnamed: Q2.1 (B), R21.1
unnamed: R2.1, R4.1, S1.A (CHANNEL_A)
unnamed: R3.1, R5.1, S1.B (CHANNEL_B)
unnamed: R24.1, U6.2 (PROG)
unnamed: R23.2, U6.7 (~CHRG)
unnamed: R22.2, U6.6 (~STDBY)
unnamed: C12.1, R14.1, R15.2, U8.8 (VBUS)
unnamed: R13.2, U8.9 (~RST)
unnamed: R12.2, U8.13 (~RXT/GPIO.1)
unnamed: R8.2, U8.14 (~TXT/GPIO.0)
unnamed: R26.1, U9.2 (CS)
unnamed: Q4.5, U9.3 (OC)
unnamed: Q4.4, U9.1 (OD)
unnamed: C17.1, R25.1, U9.5 (VCC)
unnamed: R17.2, X1.A5 (CC1)
unnamed: R16.2, X1.B5 (CC2)

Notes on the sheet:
2.8" tft spi screen
USB-C module
NRF24 module
Left and right joysticks
Schottky diode and FET for load sharing
Rotary encoder
AP2112K-3.3 regulator
CP2102N USB driver
Left & right toggle switches
2 cell 18650 connector
DW01A & FS8205A
ESP32
Boot and EN push buttons
BONK RC Transmitter | Spectral Systems | CERN-OHL-P-2.0 github.com/tyke01/ CONVENTIONS GND = switched negative (P-), BAT- = raw cell negative. SPI shared: TFT (CS), nRF24 (CSN). I2C: INA226 @ 0x40. Battery current: + discharge, - charge. PWR_FLAGs are ERC-only. ESP32 Sticks/pots on ADC1 (works with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
Left & right potentiometers
INA226 module
TP4056 battery charger
Auto reset transistors

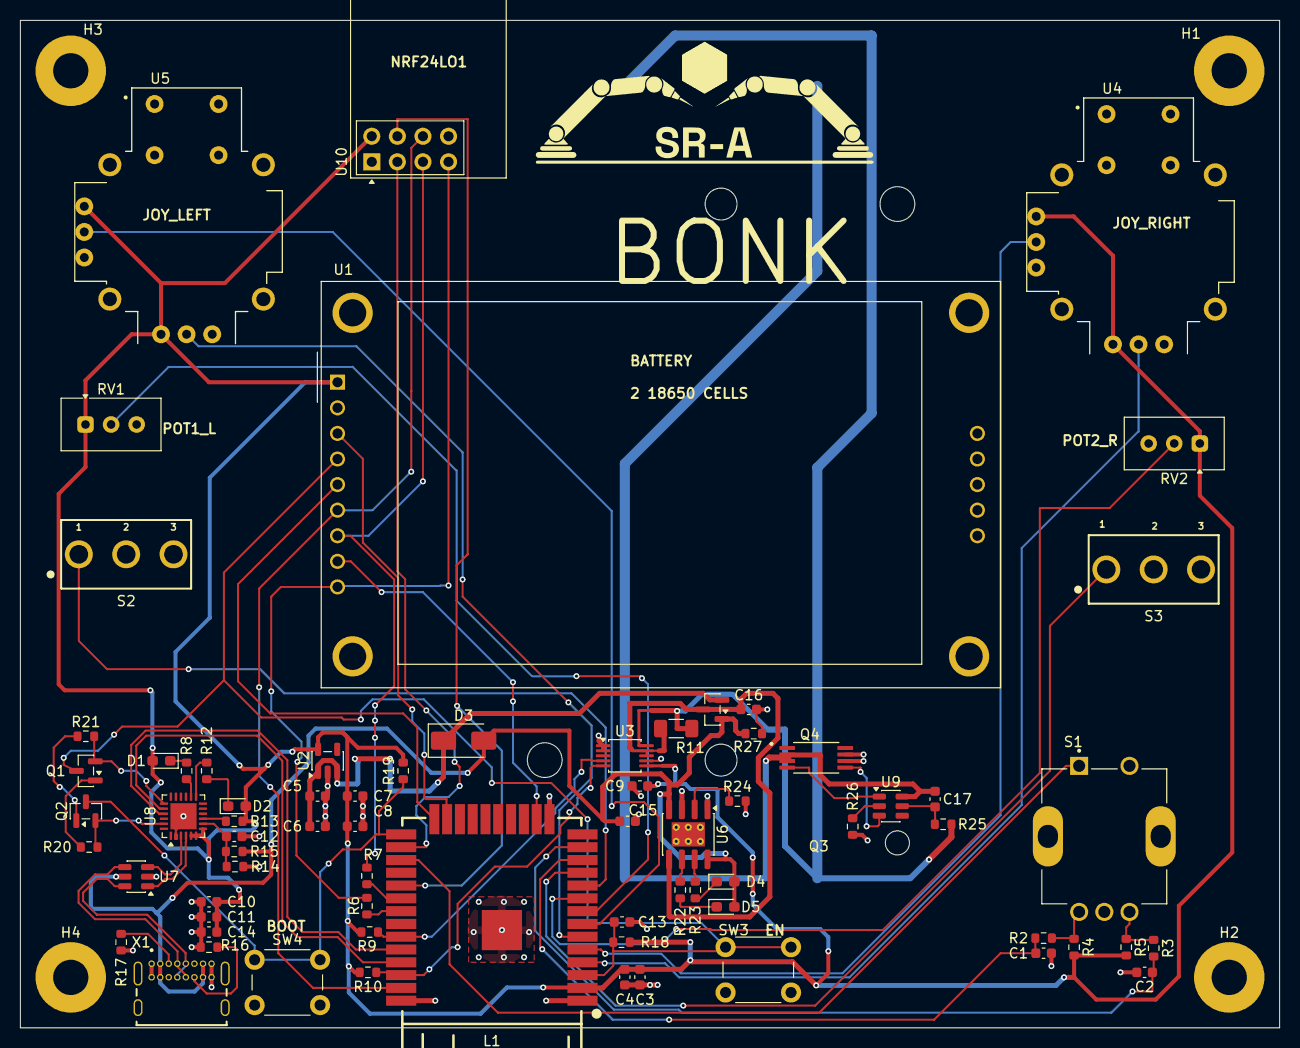
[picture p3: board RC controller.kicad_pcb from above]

Board: 4 copper layers, 125.0 x 100.0 mm, 76 parts (1 on the bottom side), 61 nets.
